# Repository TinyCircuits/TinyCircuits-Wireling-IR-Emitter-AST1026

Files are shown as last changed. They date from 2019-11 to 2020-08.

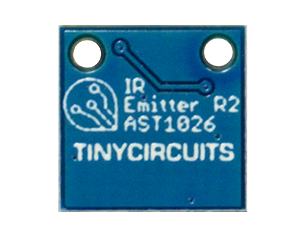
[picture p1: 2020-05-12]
images/AST1026-Learn-Photo-02.png

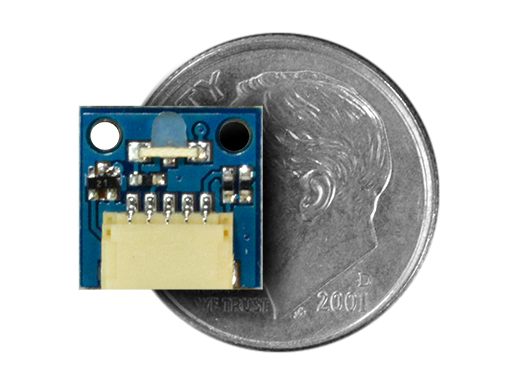
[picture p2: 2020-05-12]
images/AST1026-Product-Photo-03.png

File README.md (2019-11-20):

# TinyCircuits Wireling IR Emitter
# AST1026 Rev2

The design files are located under design_files/ for the TinyCircuits AST1026 Rev 2 PCB. This Wireling features an 880 nm IR LED and can be used with our 38kHz IR Receiver Wireling or other IR receivers (like television sets). 

Format is in Cadsoft Eagle format - Eagle version 6.2 was used for the original design.

For more infomation on this, check out the product page at TinyCircuits.com

# License:

Design by TinyCircuits.
All design files are released under the Creative Commons Attribution Share-Alike 3.0 License, see the following link for details: http://creativecommons.org/licenses/by-sa/3.0

All text above must be included in any redistribution or derived design

This project uses designs and concepts developed as part of the Arduino project and the LilyPad project.  The TinyCircuits design files themselves (schematics, PCB and libraries) are not directly derived from these works' design files and have been created new, however the concepts and basic architecture behind the TinyDuino and TinyLily products are derived and we thank the hard work of the organizations below for their contributions to open-source hardware:
  
Original Arduino Uno Design by Team Arduino

LilyPad Arduino Design by Leah Buechley and Sparkfun Electronics

Please support the open-source hardware community

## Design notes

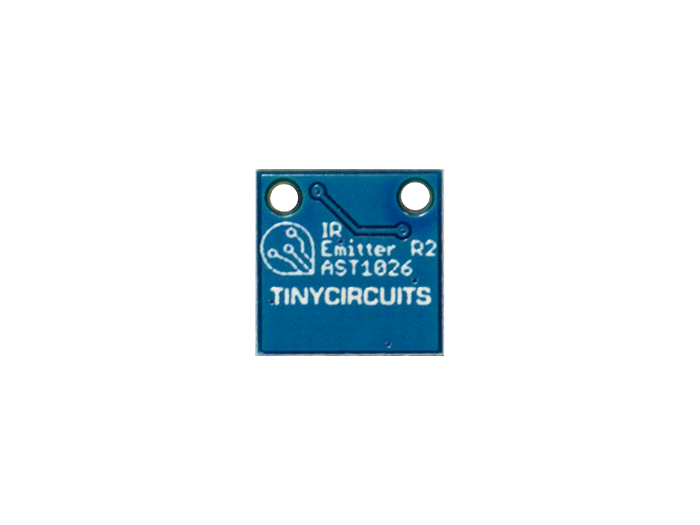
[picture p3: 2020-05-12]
images/AST1026-Product-Photo-02.png

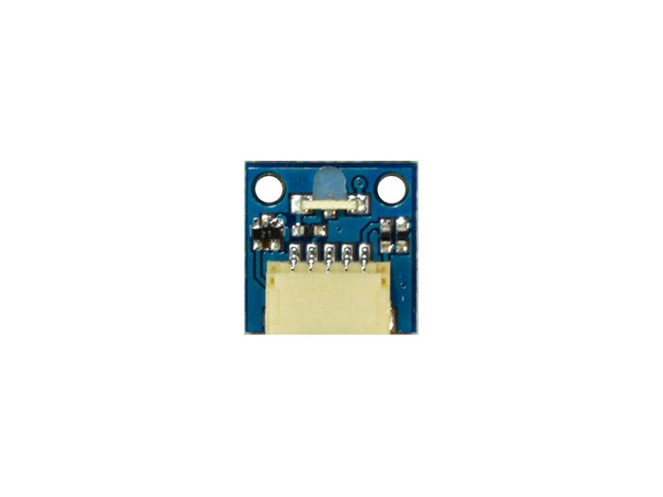
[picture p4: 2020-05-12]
images/AST1026-Product-Photo-01.png

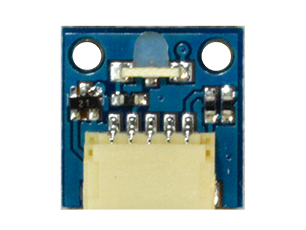
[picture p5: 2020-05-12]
images/AST1026-Learn-Photo-01.png

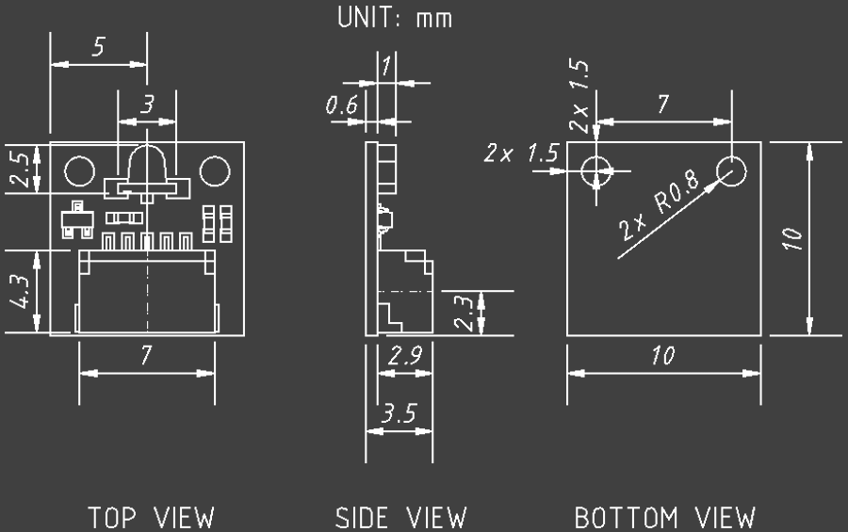
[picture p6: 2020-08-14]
cad/Wireling_IR_EMITTER_AST1026_REV2-DETAILED_DRAWING_COMPACT-PNG.png

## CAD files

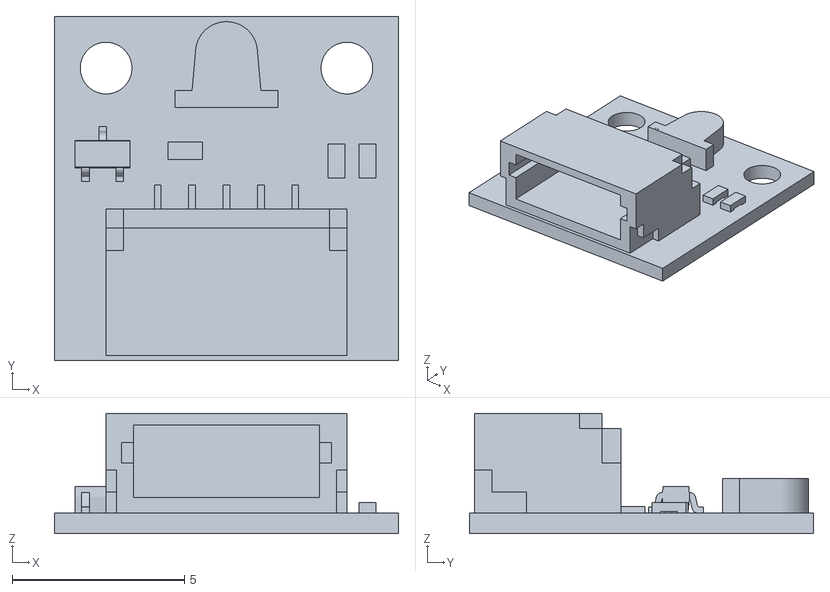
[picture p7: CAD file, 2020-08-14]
cad/Wireling_IR_EMITTER_AST1026_REV2-STL.stl
10.0 x 10.0 x 3.49

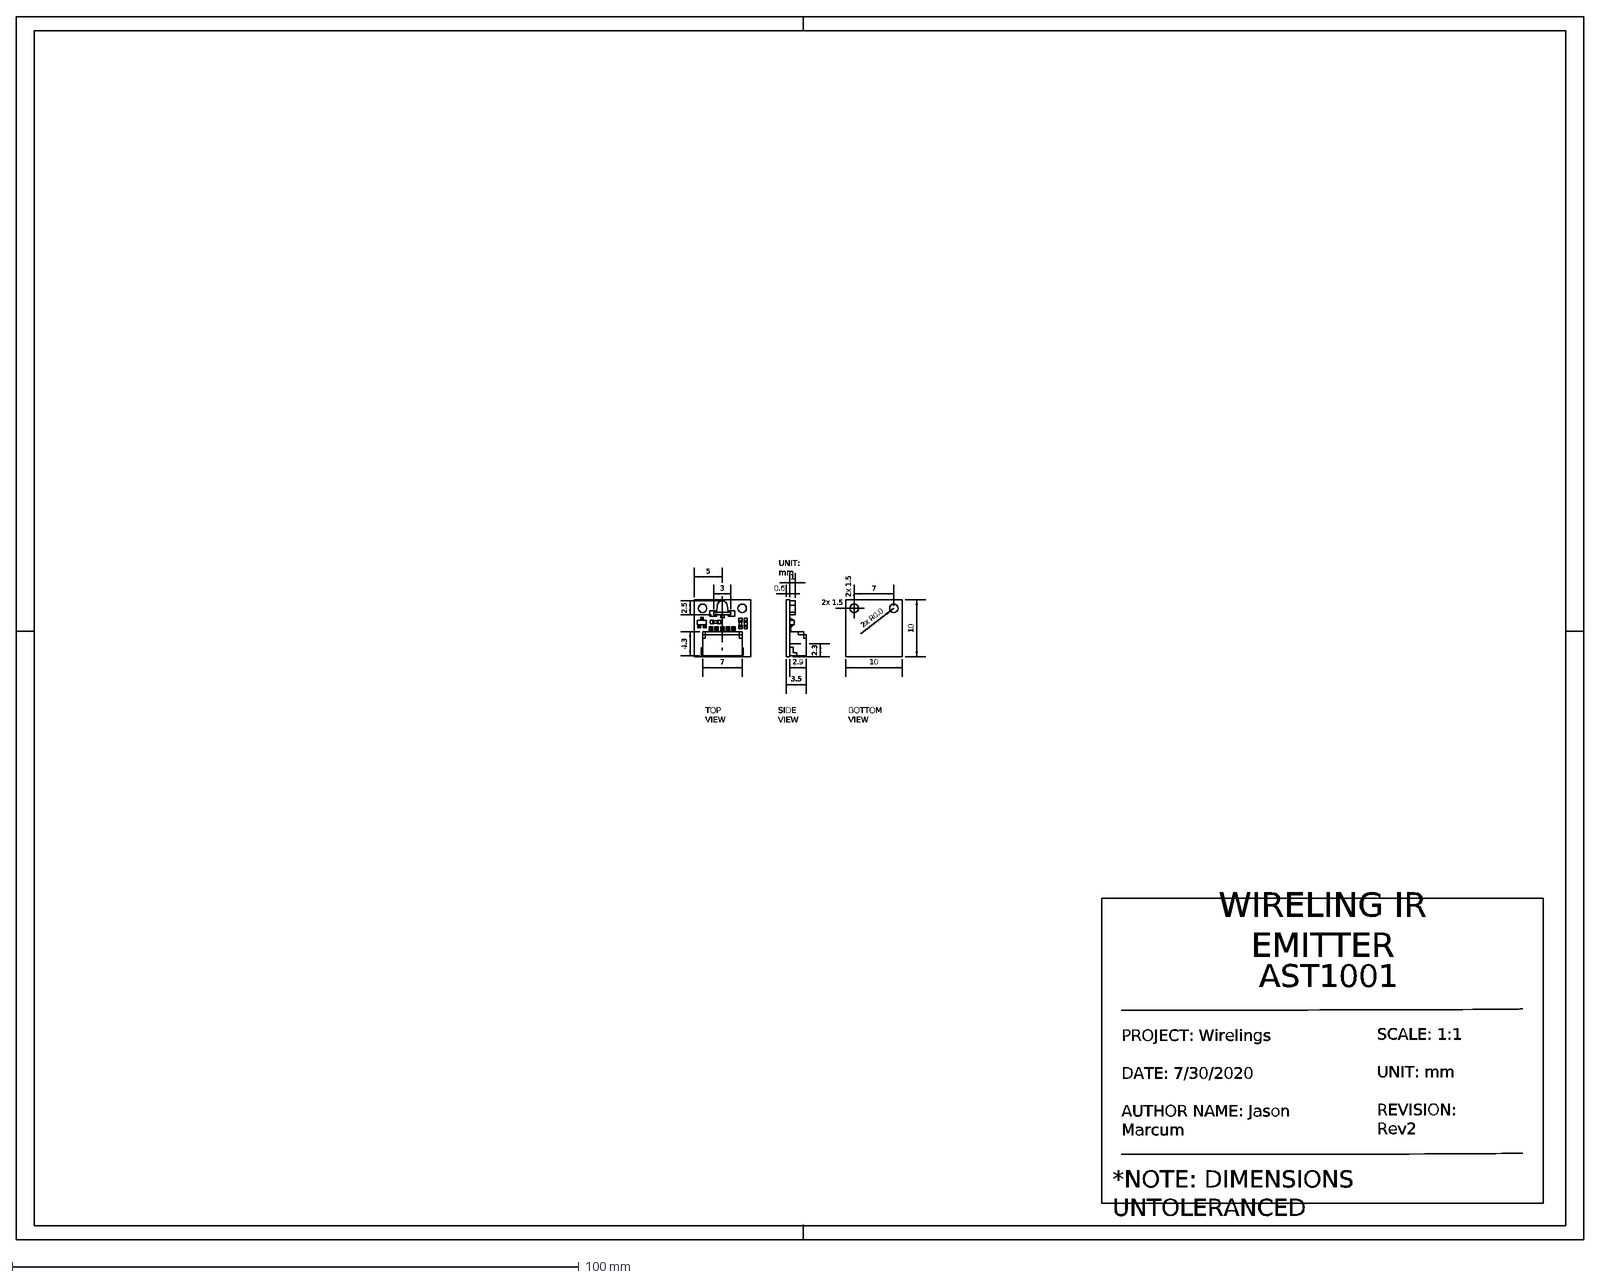
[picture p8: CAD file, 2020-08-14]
cad/Wireling_IR_EMITTER_AST1026_REV2-DETAILED_DRAWING-DXF.dxf
*NOTE: DIMENSIONS UNTOLERANCED
AST1001
TOP VIEW
BOTTOM VIEW
SIDE VIEW
UNIT: mm
7
4.3
3
2.5
5
2.9
3.5
2.3
0.6
2x 1.5
2x R0.8
10
1
WIRELING IR EMITTER
SCALE: 1:1 UNIT: mm REVISION: Rev2
PROJECT: Wirelings DATE: 7/30/2020 AUTHOR NAME: Jason Marcum

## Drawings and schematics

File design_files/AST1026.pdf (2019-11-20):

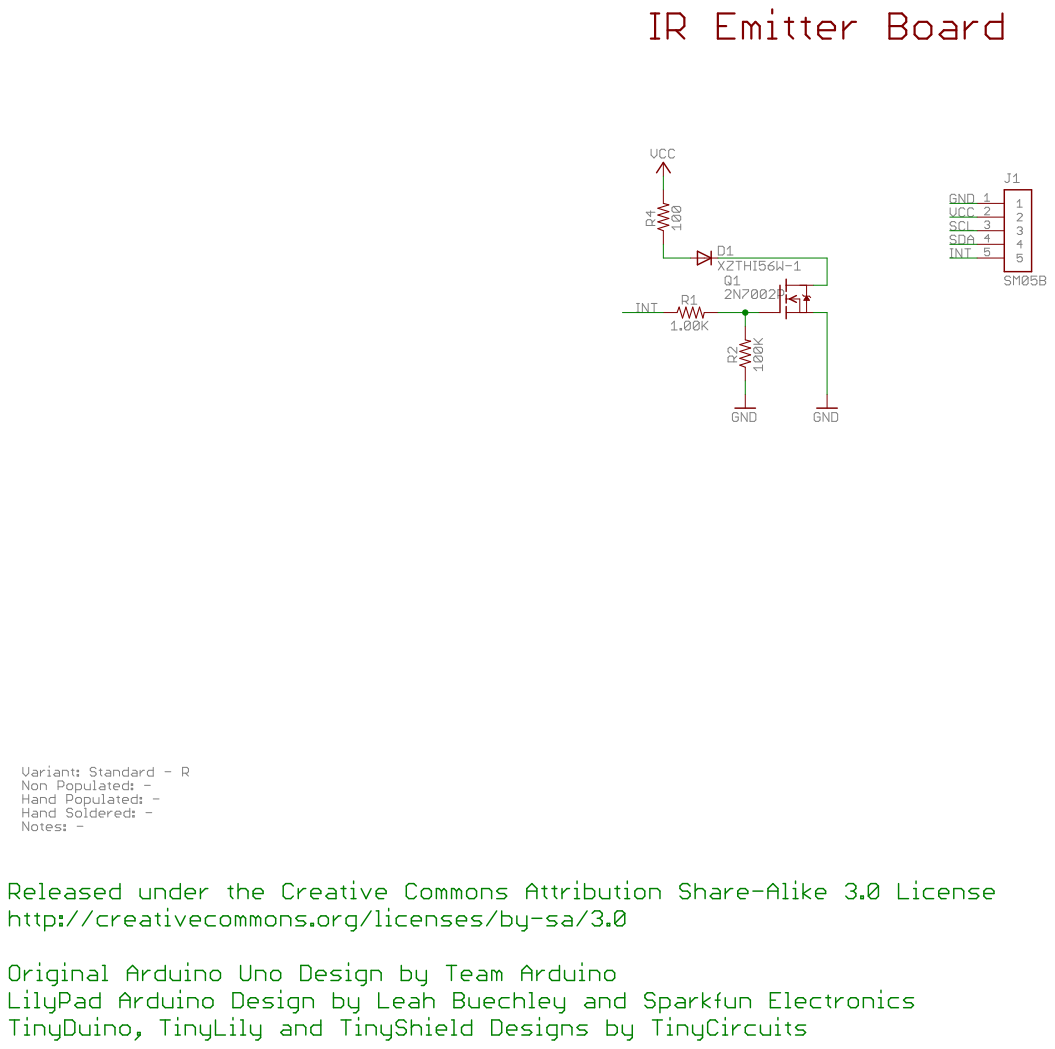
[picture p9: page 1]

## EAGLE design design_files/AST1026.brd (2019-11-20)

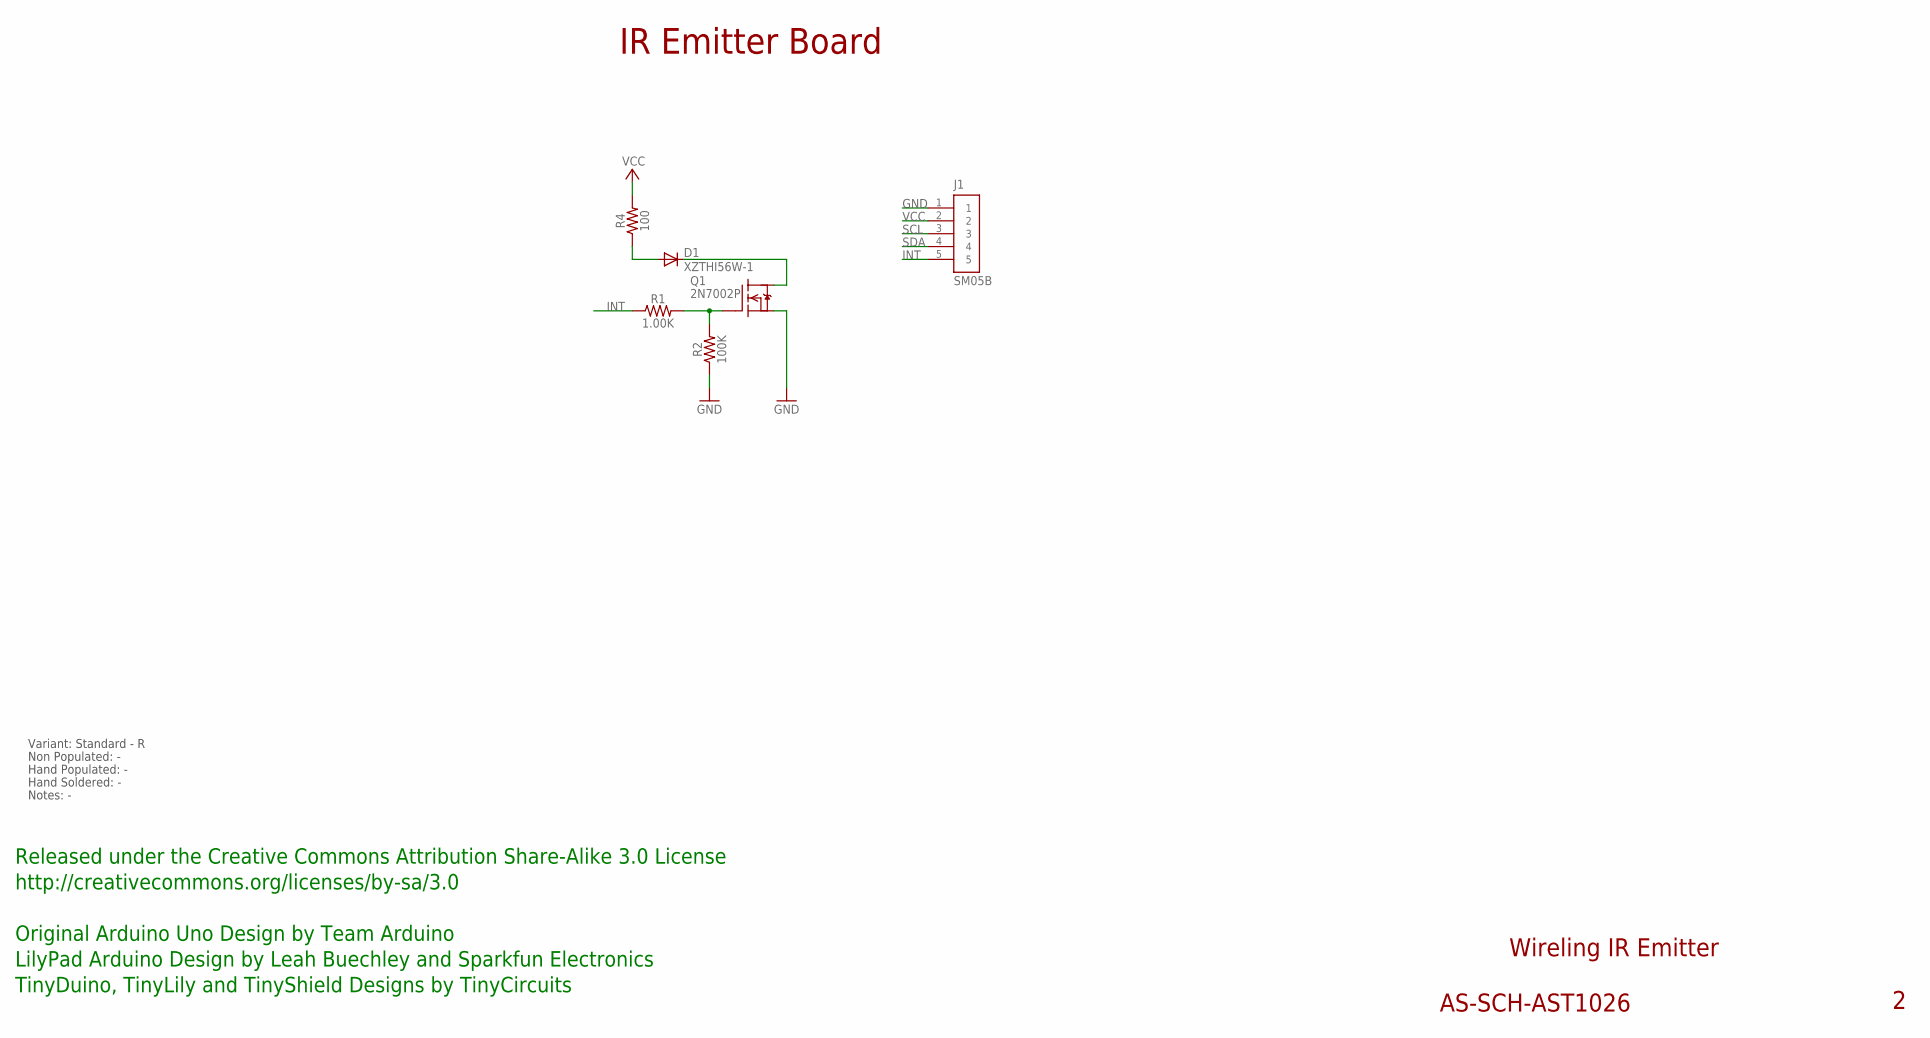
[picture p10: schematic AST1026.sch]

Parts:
D1: XZTHI56W-1; LED_SIDE_3.0X1.0; PARTNO AS-ITM-00551
J1: SM05B; JST_SH_5X1_EDGE
Q1: 2N7002P; SOT-416; PARTNO AS-ITM-00110
R1: 1.00K; 0402
R2: 100K; 0402
R4: 100; 0402

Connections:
GND: J1.1, Q1.2 (S), R2.1
INT: J1.5, R1.1
unnamed: D1.A, R4.1
unnamed: D1.C, Q1.3 (D)
unnamed: Q1.1 (G), R1.2, R2.2
SCL: J1.3
SDA: J1.4
VCC: J1.2, R4.2

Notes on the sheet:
Wireling IR Emitter
AS-SCH-AST1026
IR Emitter Board
Released under the Creative Commons Attribution Share-Alike 3.0 License
http://creativecommons.org/licenses/by-sa/3.0
Original Arduino Uno Design by Team Arduino
TinyDuino, TinyLily and TinyShield Designs by TinyCircuits
LilyPad Arduino Design by Leah Buechley and Sparkfun Electronics
Non Populated: -
Hand Populated: -
Hand Soldered: -
Notes: -
Variant: Standard - R

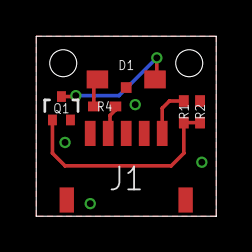
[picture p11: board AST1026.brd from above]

Board: 2 copper layers, 10.0 x 10.0 mm, 7 parts (0 on the bottom side), 6 nets.

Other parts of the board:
U$1: DOCFIELD-TINYCIRCUITS-PCB

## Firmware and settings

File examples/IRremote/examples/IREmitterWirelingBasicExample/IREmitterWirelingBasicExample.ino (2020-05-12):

/************************************************************************
   IR Emitter Wireling Example
   This code shows how to use the IR Emitter Wireling to transmit NEC
   IR codes(in this example, the codes used with TinyTV).

   Hardware by: TinyCircuits
   Written by: Ben Rose for TinyCircuits

   Initiated: 11/20/2019
   Updated: 05/06/2020
 ************************************************************************/

#include <IRremote.h>
#include <Wire.h>
#include <Wireling.h>

#if defined (ARDUINO_ARCH_AVR)
#define SerialMonitorInterface Serial
#elif defined(ARDUINO_ARCH_SAMD)
#define SerialMonitorInterface SerialUSB
#endif

// Define codes as 32 bit unsigned integers
uint32_t powerCode = 0x10AF8877;
uint32_t volUpCode = 0x10AF708F;
uint32_t volDownCode = 0x10AFB04F;
uint32_t chanUpCode = 0x10AF807F;
uint32_t chanDownCode = 0x10AF20DF;
uint32_t muteCode = 0x10AFF00F;

// Receive and transmit can be done on any IO pin. Pick A0-A3 for Wireling ports 0-3.
int TX_PIN = A0;

IRsend irsend(TX_PIN);

void setup(void) {
  SerialMonitorInterface.begin(9600);
  Wire.begin();
  Wireling.begin();
  while (!SerialMonitorInterface && millis() < 5000); //This will block for 5 seconds or until the Serial Monitor is opened on TinyScreen+/TinyZero platform!
}


void loop() {
  SerialMonitorInterface.println("Sending powerCode!");
  noInterrupts();
  irsend.sendNEC(powerCode, 32);
  interrupts();
  delay(1000);
  SerialMonitorInterface.println("Sending muteCode!");
  noInterrupts();
  irsend.sendNEC(muteCode, 32);
  interrupts();
  delay(1000);
}

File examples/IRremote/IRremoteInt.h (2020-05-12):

/*
 * IRremote
 * Version 0.1 July, 2009
 * Copyright 2009 Ken Shirriff
 * For details, see http://arcfn.com/2009/08/multi-protocol-infrared-remote-library.html
 *
 * Modified by Paul Stoffregen <paul@pjrc.com> to support other boards and timers
 *
 * Interrupt code based on NECIRrcv by Joe Knapp
 * http://www.arduino.cc/cgi-bin/yabb2/YaBB.pl?num=1210243556
 * Also influenced by http://zovirl.com/2008/11/12/building-a-universal-remote-with-an-arduino/
 *
 * JVC and Panasonic protocol added by Kristian Lauszus (Thanks to zenwheel and other people at the original blog post)
 */

#ifndef IRremoteint_h
#define IRremoteint_h

#if defined(ARDUINO) && ARDUINO >= 100
#include <Arduino.h>
#else
#include <WProgram.h>
#endif

// define which timer to use
//
// Uncomment the timer you wish to use on your board.  If you
// are using another library which uses timer2, you have options
// to switch IRremote to use a different timer.

// Arduino Mega
#if defined(__AVR_ATmega1280__) || defined(__AVR_ATmega2560__)
  //#define IR_USE_TIMER1   // tx = pin 11
  #define IR_USE_TIMER2     // tx = pin 9
  //#define IR_USE_TIMER3   // tx = pin 5
  //#define IR_USE_TIMER4   // tx = pin 6
  //#define IR_USE_TIMER5   // tx = pin 46

// Teensy 1.0
#elif defined(__AVR_AT90USB162__)
  #define IR_USE_TIMER1     // tx = pin 17

// Teensy 2.0
#elif defined(__AVR_ATmega32U4__)
  //#define IR_USE_TIMER1   // tx = pin 14
  //#define IR_USE_TIMER3   // tx = pin 9
  #define IR_USE_TIMER4_HS  // tx = pin 10

// Teensy++ 1.0 & 2.0
#elif defined(__AVR_AT90USB646__) || defined(__AVR_AT90USB1286__)
  //#define IR_USE_TIMER1   // tx = pin 25
  #define IR_USE_TIMER2     // tx = pin 1
  //#define IR_USE_TIMER3   // tx = pin 16

// Sanguino
#elif defined(__AVR_ATmega644P__) || defined(__AVR_ATmega644__)
  //#define IR_USE_TIMER1   // tx = pin 13
  #define IR_USE_TIMER2     // tx = pin 14

// Atmega8
#elif defined(__AVR_ATmega8P__) || defined(__AVR_ATmega8__)
  #define IR_USE_TIMER1   // tx = pin 9

#elif defined( __AVR_ATtinyX4__ )
  #define IR_USE_TIMER1   // tx = pin 6

// SAMD21
#elif defined(__SAMD21G18A__)

#define ISR(TIMER_INTR_NAME) void TC4_Handler()
#define sei() interrupts()
#define cli() noInterrupts()
#define TIMER_PWM_PIN -1
#define TIMER_RESET TCx->COUNT16.INTFLAG.bit.MC0 = 1
#define TIMER_DISABLE_PWM
#define TIMER_ENABLE_INTR
#define TIMER_DISABLE_INTR
#define TIMER_INTR_NAME
#define TIMER_CONFIG_KHZ(val)

// Arduino Duemilanove, Diecimila, LilyPad, Mini, Fio, etc
#else
  //#define IR_USE_TIMER1   // tx = pin 9
  #define IR_USE_TIMER2     // tx = pin 3
#endif



#ifdef F_CPU
#define SYSCLOCK F_CPU     // main Arduino clock
#else
#define SYSCLOCK 16000000  // main Arduino clock
#endif

#define ERR 0
#define DECODED 1


// defines for setting and clearing register bits
#ifndef cbi
#define cbi(sfr, bit) (_SFR_BYTE(sfr) &= ~_BV(bit))
#endif
#ifndef sbi
#define sbi(sfr, bit) (_SFR_BYTE(sfr) |= _BV(bit))
#endif

// Pulse parms are *50-100 for the Mark and *50+100 for the space
// First MARK is the one after the long gap
// pulse parameters in usec
#define NEC_HDR_MARK  9000
#define NEC_HDR_SPACE 4500
#define NEC_BIT_MARK  560
#define NEC_ONE_SPACE 1600
#define NEC_ZERO_SPACE  560
#define NEC_RPT_SPACE 2250

#define SONY_HDR_MARK 2400
#define SONY_HDR_SPACE  600
#define SONY_ONE_MARK 1200
#define SONY_ZERO_MARK  600
#define SONY_RPT_LENGTH 45000
#define SONY_DOUBLE_SPACE_USECS  500  // usually ssee 713 - not using ticks as get number wrapround

// SA 8650B
#define SANYO_HDR_MARK  3500  // seen range 3500
#define SANYO_HDR_SPACE 950 //  seen 950
#define SANYO_ONE_MARK  2400 // seen 2400  
#define SANYO_ZERO_MARK 700 //  seen 700
#define SANYO_DOUBLE_SPACE_USECS  800  // usually ssee 713 - not using ticks as get number wrapround
#define SANYO_RPT_LENGTH 45000

// Mitsubishi RM 75501
// 14200 7 41 7 42 7 42 7 17 7 17 7 18 7 41 7 18 7 17 7 17 7 18 7 41 8 17 7 17 7 18 7 17 7 

// #define MITSUBISHI_HDR_MARK  250  // seen range 3500
#define MITSUBISHI_HDR_SPACE  350 //  7*50+100
#define MITSUBISHI_ONE_MARK 1950 // 41*50-100
#define MITSUBISHI_ZERO_MARK  750 // 17*50-100
// #define MITSUBISHI_DOUBLE_SPACE_USECS  800  // usually ssee 713 - not using ticks as get number wrapround
// #define MITSUBISHI_RPT_LENGTH 45000


#define RC5_T1    889
#define RC5_RPT_LENGTH  46000

#define RC6_HDR_MARK  2666
#define RC6_HDR_SPACE 889
#define RC6_T1    444
#define RC6_RPT_LENGTH  46000

#define SHARP_BIT_MARK 245
#define SHARP_ONE_SPACE 1805
#define SHARP_ZERO_SPACE 795
#define SHARP_GAP 600000
#define SHARP_TOGGLE_MASK 0x3FF
#define SHARP_RPT_SPACE 3000

#define DISH_HDR_MARK 400
#define DISH_HDR_SPACE 6100
#define DISH_BIT_MARK 400
#define DISH_ONE_SPACE 1700
#define DISH_ZERO_SPACE 2800
#define DISH_RPT_SPACE 6200
#define DISH_TOP_BIT 0x8000

#define PANASONIC_HDR_MARK 3502
#define PANASONIC_HDR_SPACE 1750
#define PANASONIC_BIT_MARK 502
#define PANASONIC_ONE_SPACE 1244
#define PANASONIC_ZERO_SPACE 400

#define JVC_HDR_MARK 8000
#define JVC_HDR_SPACE 4000
#define JVC_BIT_MARK 600
#define JVC_ONE_SPACE 1600
#define JVC_ZERO_SPACE 550
#define JVC_RPT_LENGTH 60000

#define SHARP_BITS 15
#define DISH_BITS 16

#define TOLERANCE 25  // percent tolerance in measurements
#define LTOL (1.0 - TOLERANCE/100.) 
#define UTOL (1.0 + TOLERANCE/100.) 

#define _GAP 5000 // Minimum map between transmissions
#define GAP_TICKS (_GAP/USECPERTICK)

#define TICKS_LOW(us) (int) (((us)*LTOL/USECPERTICK))
#define TICKS_HIGH(us) (int) (((us)*UTOL/USECPERTICK + 1))

#ifndef DEBUG
int MATCH(int measured, int desired) {return measured >= TICKS_LOW(desired) && measured <= TICKS_HIGH(desired);}
int MATCH_MARK(int measured_ticks, int desired_us) {return MATCH(measured_ticks, (desired_us + MARK_EXCESS));}
int MATCH_SPACE(int measured_ticks, int desired_us) {return MATCH(measured_ticks, (desired_us - MARK_EXCESS));}
// Debugging versions are in IRremote.cpp
#endif

// receiver states
#define STATE_IDLE     2
#define STATE_MARK     3
#define STATE_SPACE    4
#define STATE_STOP     5

// information for the interrupt handler
typedef struct {
  uint8_t recvpin;           // pin for IR data from detector
  uint8_t rcvstate;          // state machine
  uint8_t blinkflag;         // TRUE to enable blinking of pin 13 on IR processing
  unsigned int timer;     // state timer, counts 50uS ticks.
  unsigned int rawbuf[RAWBUF]; // raw data
  uint8_t rawlen;         // counter of entries in rawbuf
} 
irparams_t;

// Defined in IRremote.cpp
extern volatile irparams_t irparams;

// IR detector output is active low
#define MARK  0
#define SPACE 1

#define TOPBIT 0x80000000

#define NEC_BITS 32
#define SONY_BITS 12
#define SANYO_BITS 12
#define MITSUBISHI_BITS 16
#define MIN_RC5_SAMPLES 11
#define MIN_RC6_SAMPLES 1
#define PANASONIC_BITS 48
#define JVC_BITS 16
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
